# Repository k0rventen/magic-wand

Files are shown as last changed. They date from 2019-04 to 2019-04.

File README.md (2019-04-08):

# Magic wand

#### Be like Harry and control anything with your magic wand !

[]()



The wand detects when it's being moved around and sends a message to the power bar, which toggles the according outlet (here the "raised" state toggles the lamp on/off).

## The emitter (magic wand)

The wand is an embbeded system composed of :

- an Arduino Nano that controls everything,
- an accelerometer and gyro (MPU 6050),
- a RF 433MHz emitter,
- a 9V battery,
- a LED,
- some magical stuff because it's a magic wand.

Here is an view of the electronic inside the wand :

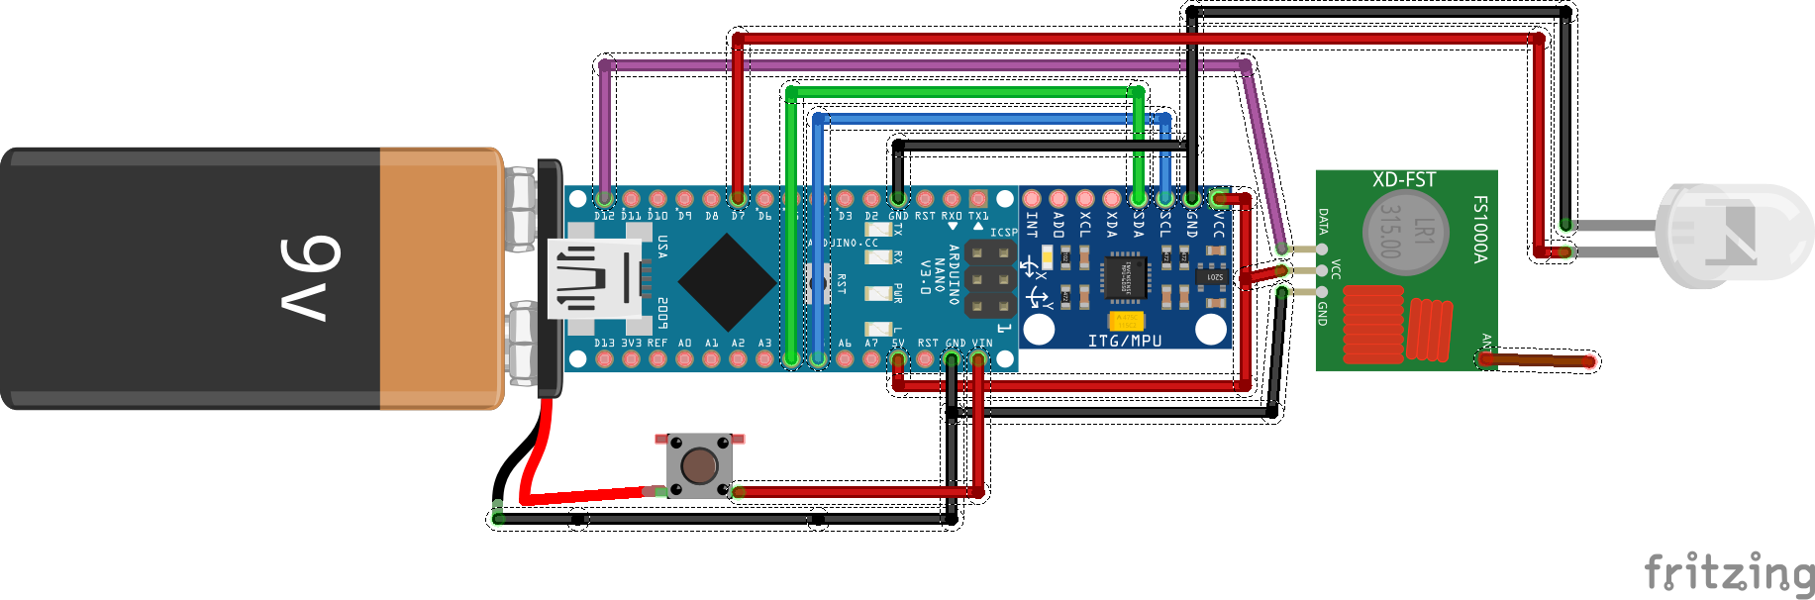
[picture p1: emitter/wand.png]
 

Once initialized (which takes about .8s), the wand continually checks its position. If it detects being raised, lowered, swung left or right, it sends a message to the power bar.

## The receiver (power bar)

The Receiver is a 4 outlets power bar. On top of the traditional wiring for AC, it also includes :

- An Arduino Uno,
- A RF433MHz receiver,
- 4 250V relays

Below is the electronic diagram : 

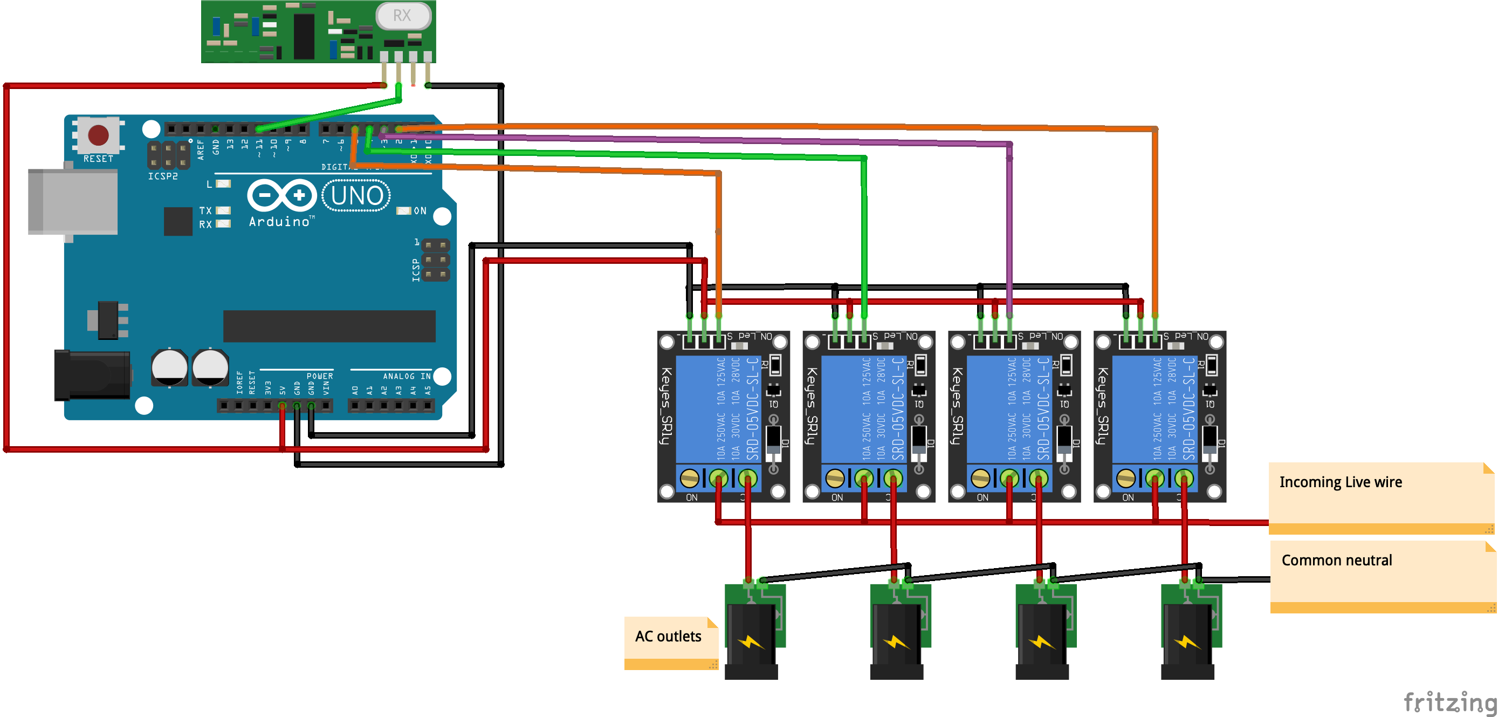
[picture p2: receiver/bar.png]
 

Each relay is connected as follows : 

- Common incoming live wire on C (Common),
- Separate outgoing live wire to the outlet on NC (Normaly Closed)

# Install

The project was made using Platform.io. 
If you are using it too, just open the two folders `emitter` and `receiver` in VSCode, and everything will be done automagically.

If using the Arduino IDE, you will first need to install the `VirtualWire` library.
Then, open the two `src` subfolders in the IDE and you will be able to compile/upload.

# License & Credits

Code and schematics are MIT.

Thx to Tockn for the [MPU6050 library](https://github.com/tockn/MPU6050_tockn). His lib included in this project is slightly tweaked to be faster during initialization, but kudos to him.

And thx to Harry for the idea.

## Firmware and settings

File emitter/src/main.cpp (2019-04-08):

#include "Arduino.h" // Default lib
#include "MPU6050_tockn.h" // For the MPU
#include <Wire.h> // Also for the MPU
#include <VirtualWire.h> // For the RF 433MHz

//#define DEBUG ; // Use for Serial verbose Debugging (comment for silent/real use)

MPU6050 mpu6050(Wire);

float roll, pitch, yaw;
const int LedPin = 7;
const int transmitPin = 12;
int led;


// Set the color for the Status LED
// 0 is off
// 1 is up and running
void setLedColor(int led_status) {
  digitalWrite(LedPin, led_status);
}

// A struct that will be sent over RF433
typedef struct {
  int action;
} Package;

// Routine called to send the package via RF433
void sendAction(int val) {
  Package mypackage;
  mypackage.action = val;
  vw_send((byte *)&mypackage, sizeof(mypackage));
  vw_wait_tx();
}

// Setup of all the various systems
void setup() {
#ifdef DEBUG
  // Set Serial for debugging
  Serial.begin(38400);
#endif

  // Set MPU
  vw_set_tx_pin(transmitPin);
  vw_setup(500);       // Bits per sec
  Wire.begin();
  mpu6050.begin();
  mpu6050.calcGyroOffsets(false);

  // Set RF 433 & Status LED
  pinMode(transmitPin, OUTPUT); // 433MHz
  pinMode(LedPin, OUTPUT); // Led

  //Once all is initialized, light up the LED
  setLedColor(1);
}

// The actual main(), that recursively checks for patterns and send
// the command to the receiver
void loop() {
  delay(80);
  mpu6050.update();

  // Yaw, pitch and roll (how is the sensor in space ?)
  pitch = mpu6050.getAngleX();
  roll = mpu6050.getAngleY();
  yaw = mpu6050.getAngleZ();

#ifdef DEBUG
  Serial.print("\tPitch: "); Serial.print(pitch);
  Serial.print("\tYaw: "); Serial.print(yaw);
  Serial.print("\tRoll: "); Serial.println(roll);
#endif
  // Check for position
  // Wand straight up
  if (pitch > 75) {
    setLedColor(0);
    sendAction(1);
  }
  // Wand straight down
  else if (pitch < -75) {
    setLedColor(0);
    sendAction(2);
  }
  // Wand swung left
  else if (yaw < -60) {
    setLedColor(0);
    sendAction(3);
  }
  // Wand swung right
  else if (yaw > 60) {
    setLedColor(0);
    sendAction(4);
  }
  else{setLedColor(1);}
}

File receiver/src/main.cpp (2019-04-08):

#include <VirtualWire.h>

//#define DEBUG // For debuggin purposes, comment when uploading to the real product

// Pin used to connect the arduino to the RF transmitter
const int recv_pin = 11;

// The struct that will be transmitted (the ID of the action)
typedef struct
{
  int action;
} Package;

bool state1, state2, state3, state4; // The state of the pins, so they can be toggled
unsigned long lastDebounceTime = 0;  // the last time the output pin was toggled
unsigned long debounceDelay = 2200;  // How many ms to wait before registering again

void setup()
{
#ifdef DEBUG
  Serial.begin(9600); // Debugging only
  Serial.println("Setting up receiver..");
#endif

  // Set the pins as OUTPUT and init the states
  pinMode(LED_BUILTIN, OUTPUT);
  pinMode(2, OUTPUT);
  pinMode(3, OUTPUT);
  pinMode(4, OUTPUT);
  pinMode(5, OUTPUT);
  state1 = true;
  state2 = true;
  state3 = true;
  state4 = true;
  digitalWrite(2, state1);
  digitalWrite(3, state1);
  digitalWrite(4, state1);
  digitalWrite(5, state1);
  // Initialise the IO and ISR
  vw_setup(500); // Bits per sec
  vw_rx_start(); // Start the receiver PLL running
#ifdef DEBUG
  Serial.println("Up and running !");
#endif
}

void loop()
{
  // The recipient for the message
  Package message;
  byte taille_message = sizeof(Package);

  if (vw_get_message((byte *)&message, &taille_message)) // Non-blocking
  {

    // Debounce
    if ((millis() - lastDebounceTime) > debounceDelay)
    {
#ifdef DEBUG
      Serial.print("Received : ");
      Serial.println(message.action);
#endif
      lastDebounceTime = millis();

      // Toggle
      switch (message.action)
      {
      case 1:
        state1 = !state1;
        digitalWrite(2, state1);
        break;

      case 2:
        state2 = !state2;
        digitalWrite(3, state2);
        break;

      case 3:
        state3 = !state3;
        digitalWrite(4, state3);
        break;

      case 4:
        state4 = !state4;
        digitalWrite(5, state4);
        break;
      }
      digitalWrite(LED_BUILTIN, HIGH); // turn the LED on (HIGH is the voltage level)
      delay(50);                       // wait for a second
      digitalWrite(LED_BUILTIN, LOW);  // turn the LED off by making the voltage LOW
    }
    else
    {
      digitalWrite(LED_BUILTIN, HIGH); // turn the LED on (HIGH is the voltage level)
      delay(50);                       // wait for a second
      digitalWrite(LED_BUILTIN, LOW);
    }
  }
}
